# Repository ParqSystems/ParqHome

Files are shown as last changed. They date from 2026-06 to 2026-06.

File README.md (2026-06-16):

ParqHome is a smart home automation system that controls household appliances in real time through a combination of custom hardware, IoT protocols, and cloud infrastructure. Users toggle devices on a React Native dashboard, which publishes MQTT commands to an ESP8266 microcontroller. The ESP8266 controls relays to switch appliances instantly, and any state change syncs back through the cloud to keep the UI synchronized. Physical switches continue to work independently for local control, ensuring the system remains functional even if cloud connectivity is lost.

The system is built on a custom PCB with an ESP8266 (ESP-12F), relay driver circuits, power regulation, and protection mechanisms. Communication happens through MQTT via HiveMQ Cloud, while the backend uses Express.js with MongoDB Atlas for state management and API services. Python automation services handle reliable message routing, and a React Native frontend provides real-time device control and status updates. Every component was designed and tested to solve real-world challenges in synchronizing distributed embedded systems with cloud infrastructure.

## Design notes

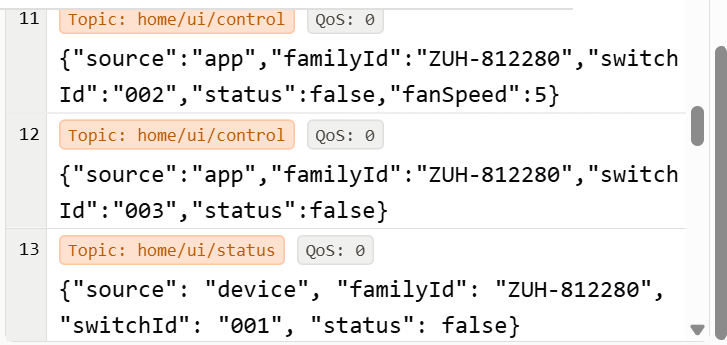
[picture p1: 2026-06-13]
Screenshot 2026-05-19 182810.png

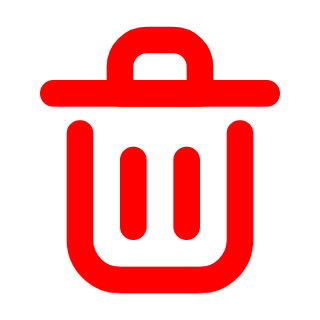
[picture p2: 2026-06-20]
Home Automation/home_automation_frontend/assets/delete-2-svgrepo-com.png

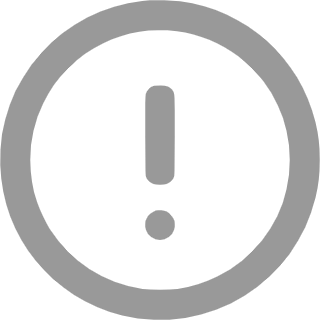
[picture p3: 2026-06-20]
Home Automation/home_automation_frontend/assets/error-16-svgrepo-com.png

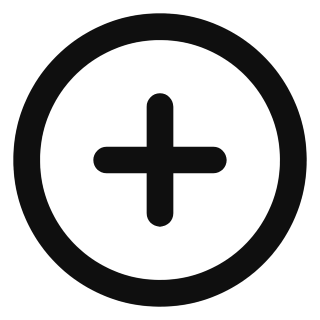
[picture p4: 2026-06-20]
Home Automation/home_automation_frontend/assets/add-ellipse-svgrepo-com.png

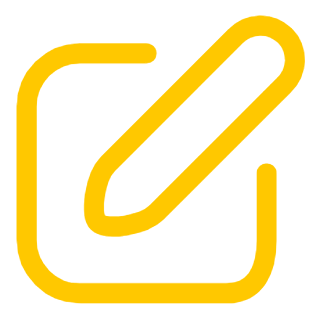
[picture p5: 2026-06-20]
Home Automation/home_automation_frontend/assets/edit-3-svgrepo-com.png

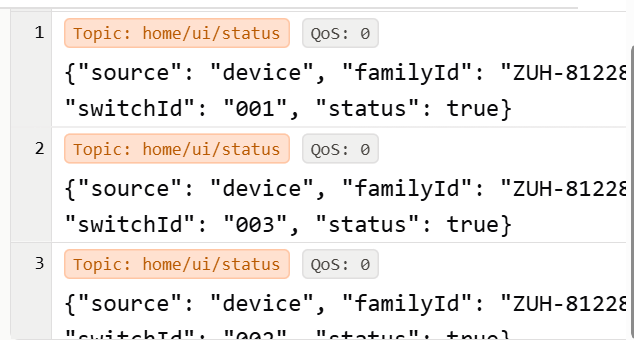
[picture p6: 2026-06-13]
Screenshot 2026-05-19 181907.png

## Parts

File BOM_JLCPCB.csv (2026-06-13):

Comment | Designator | Footprint | LCSC Part #
HLK-PM01 | U1 | HLK-PM01
5x20mm Fuse | F1 | Fuseholder_Clip-5x20mm
MOV 14D471 | MOV1 | MOV_Disc
AMS1117-3.3 | U2 | SOT-223
10uF | C1,C2 | C_ThroughHole
0.1uF | C3 | C_ThroughHole
ESP Module | U3 | ESP_Module
Relay 5V | K1, K2, K3 | Relay_THT
BC547 | Q1, Q2, Q3 | TO-92
1N4007 | D1, D2 ,D3 | DO-41
Terminal Block (2-pin) | J1, J3, J4 | TerminalBlock_2pin
Terminal Block (4-pin) | J2 | Connector_PinHeader_2.54mm:PinHeader_1x04_P2.54mm_Vertical
1k | R1 R2 R3 | Resistor_THT
10k | R4 R5 R6 | Resistor_THT
LED | LED1 LED2 | LED_THT
330? | R7 R8 | Resistor_THT
Test Point | TP1 TP2 | TestPoint

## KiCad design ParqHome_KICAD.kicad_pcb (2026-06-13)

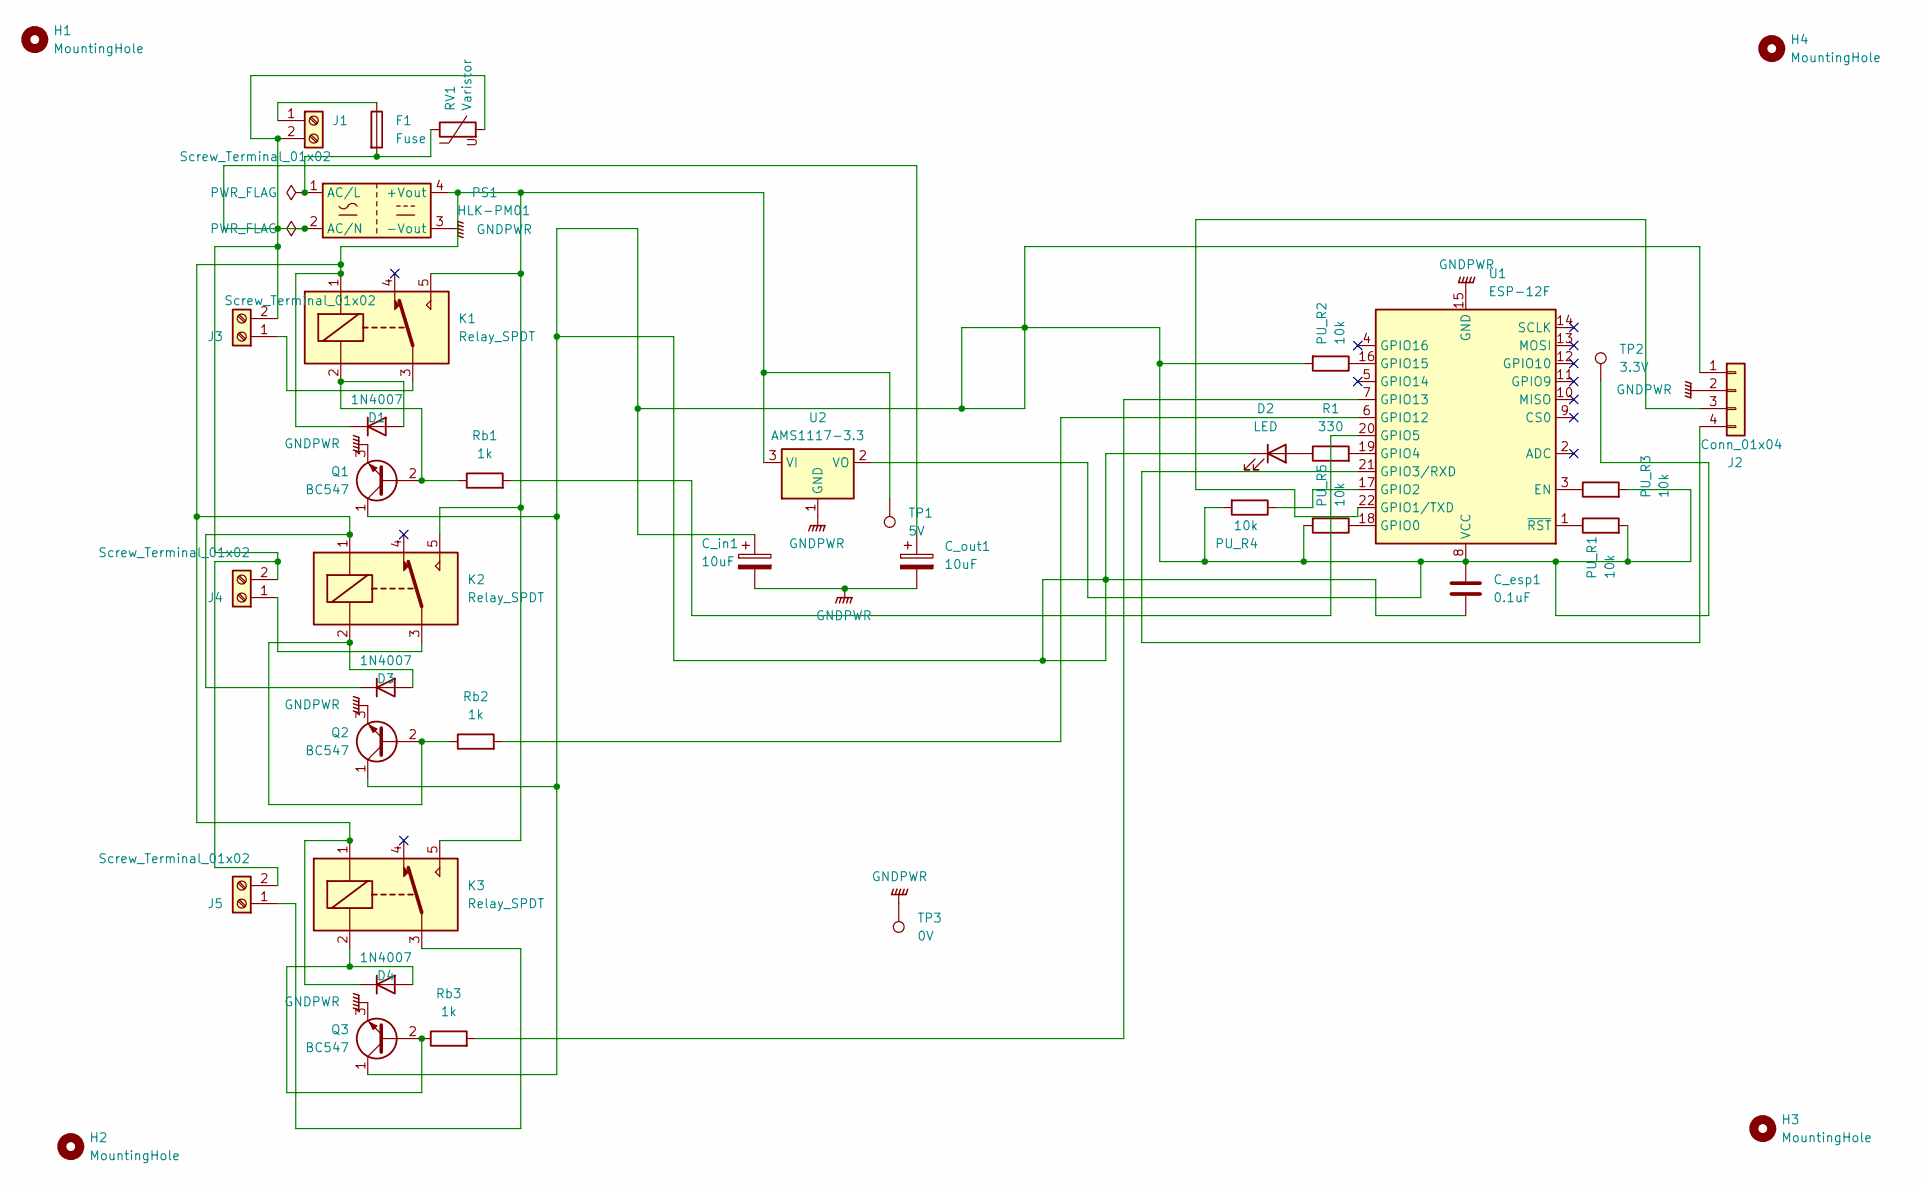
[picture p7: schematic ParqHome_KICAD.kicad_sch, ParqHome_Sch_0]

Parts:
C_esp1: 0.1uF; C_0805_2012Metric
C_in1: 10uF; CP_Radial_D6.3mm_P2.50mm
C_out1: 10uF; CP_Radial_D6.3mm_P2.50mm
D1, D3, D4: 1N4007; D_DO-41_SOD81_P10.16mm_Horizontal
D2: LED; LED_0805_2012Metric
F1: Fuse; Fuseholder_Clip-5x20mm_Littelfuse_520_Inline_P20.50x5.80mm_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
H1, H2, H3, H4: MountingHole; MountingHole_3.2mm_M3
J1, J3, J4, J5: Screw_Terminal_01x02; TerminalBlock_CUI_TB007-508-02_1x02_P5.08mm_Horizontal
J2: Conn_01x04; PinHeader_1x04_P2.54mm_Vertical
K1, K2, K3: Relay_SPDT; Relay_SPDT_SANYOU_SRD_Series_Form_C
PS1: HLK-PM01; Converter_ACDC_Hi-Link_HLK-PMxx
PU_R1, PU_R2, PU_R3, PU_R4, PU_R5: 10k; R_0805_2012Metric
Q1, Q2, Q3: BC547; TO-92_Inline
R1: 330; R_0805_2012Metric
RV1: Varistor; RV_Disc_D7mm_W3.4mm_P5mm
Rb1, Rb2, Rb3: 1k; R_0805_2012Metric
TP1: 5V; TestPoint_Bridge_Pitch2.54mm_Drill1.0mm
TP2: 3.3V; TestPoint_Bridge_Pitch2.54mm_Drill1.0mm
TP3: 0V; TestPoint_Bridge_Pitch2.54mm_Drill1.0mm
U1: ESP-12F; ESP-12E
U2: AMS1117-3.3; SOT-223-3_TabPin2

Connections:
GNDPWR: C_in1.2, C_out1.2, J2.2, PS1.3 (-Vout), Q1.3 (E), Q2.3 (E), Q3.3 (E), TP3.1, U1.15 (GND), U2.1 (GND)
unnamed: D1.2 (A), K1.2, Q1.2 (B), Rb1.1
unnamed: D1.1 (K), D3.1 (K), D4.1 (K), K1.1, K1.5, K2.1, K2.5, K3.1, K3.5, PS1.4 (+Vout), TP1.1, U2.3 (VI)
unnamed: D2.2 (A), R1.1
unnamed: C_esp1.1, C_esp1.2, C_in1.1, D2.1 (K), J2.1, PU_R1.2, PU_R2.2, PU_R3.2, PU_R4.2, PU_R5.2, Q1.1 (C), Q2.1 (C), Q3.1 (C), TP2.1, U1.8 (VCC), U2.2 (VO)
unnamed: D3.2 (A), K2.2, Q2.2 (B), Rb2.1
unnamed: D4.2 (A), K3.2, Q3.2 (B), Rb3.1
unnamed: F1.1, J1.1
unnamed: C_out1.1, J1.2, J3.2, J4.2, J5.2, PS1.2 (AC/N), RV1.2
unnamed: J2.3, U1.22 (GPIO1/TXD)
unnamed: J2.4, U1.21 (GPIO3/RXD)
unnamed: J3.1, K1.3
unnamed: J4.1, K2.3
unnamed: J5.1, K3.3
unnamed: F1.2, PS1.1 (AC/L), RV1.1
unnamed: PU_R3.1, U1.3 (EN)
unnamed: PU_R5.1, U1.18 (GPIO0)
unnamed: PU_R4.1, U1.17 (GPIO2)
unnamed: R1.2, U1.19 (GPIO4)
unnamed: Rb1.2, U1.20 (GPIO5)
unnamed: Rb2.2, U1.6 (GPIO12)
unnamed: Rb3.2, U1.7 (GPIO13)
unnamed: PU_R2.1, U1.16 (GPIO15)
unnamed: PU_R1.1, U1.1 (~RST)

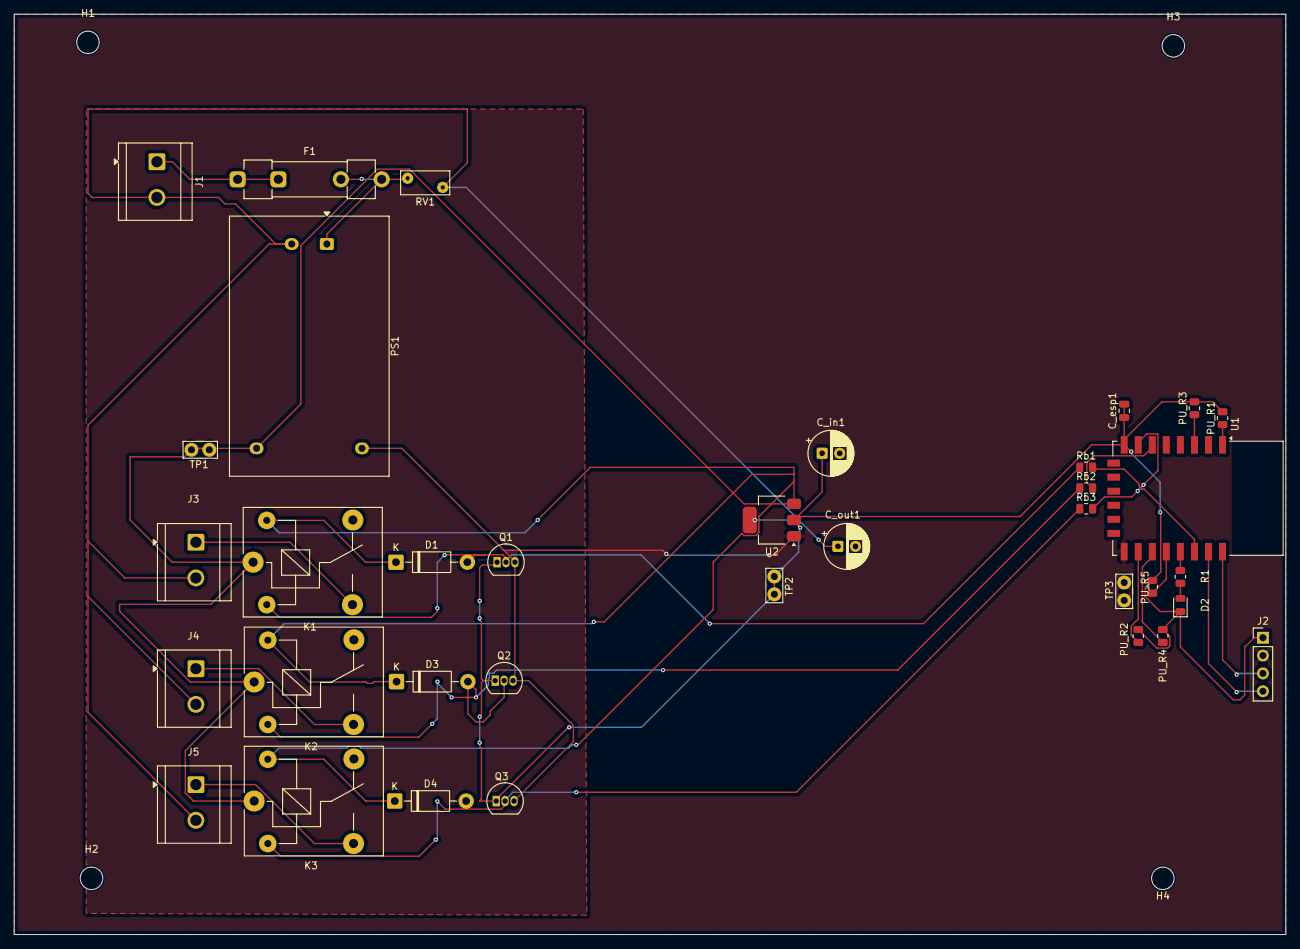
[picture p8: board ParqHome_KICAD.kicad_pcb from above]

Board: 2 copper layers, 181.0 x 131.0 mm, 39 parts (0 on the bottom side), 24 nets.

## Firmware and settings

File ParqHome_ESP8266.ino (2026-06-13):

#include <ESP8266WiFi.h>
#include <WiFiClientSecure.h>
#include <PubSubClient.h>

///////////////////////
// 🔌 PIN DEFINITIONS
///////////////////////
#define RELAY1 5
#define RELAY2 12
#define RELAY3 13

#define SW1 14
#define SW2 4
#define SW3 2

///////////////////////
// 📶 WIFI
///////////////////////
const char* ssid = "ICN 1st floor 4";
const char* password = "Akash@445";

///////////////////////
// 🌐 MQTT
///////////////////////
const char* mqtt_server = "8644400fc9e448468233fc0f9be265a0.s1.eu.hivemq.cloud";
const int mqtt_port = 8883;

const char* mqtt_user = "ParqHome_Hardware";
const char* mqtt_pass = "ParqHome_Hardware@123";

///////////////////////
// 👨‍👩‍👧 FAMILY ID
///////////////////////
const char* familyId = "ZUH-812280";

///////////////////////
// 📡 TOPICS
///////////////////////
const char* topic_control = "home/esp/control";
const char* topic_status  = "home/esp/status";

///////////////////////
// 🧠 STATE
///////////////////////
bool light1State = false;
bool light2State = false;
bool fanState    = false;

///////////////////////
// ⏱️ DEBOUNCE
///////////////////////
unsigned long lastDebounceTime[3] = {0,0,0};
const int debounceDelay = 200;

int lastSwitchState[3] = {HIGH, HIGH, HIGH};
bool pressed[3] = {false, false, false};

///////////////////////
// CLIENTS
///////////////////////
WiFiClientSecure espClient;
PubSubClient client(espClient);

///////////////////////
// 🔌 RELAY CONTROL
///////////////////////
void updateRelay(int pin, bool state) {
  digitalWrite(pin, state ? LOW : HIGH);
}

void applyStates() {
  updateRelay(RELAY1, light1State);
  updateRelay(RELAY2, light2State);
  updateRelay(RELAY3, fanState);
}

///////////////////////
// 📤 SEND STATUS
///////////////////////
void publishState() {

  String msg1 = "{\"source\":\"device\",\"familyId\":\"" + String(familyId) + "\",\"switchId\":\"001\",\"status\":" + String(light1State ? "true" : "false") + "}";
  String msg2 = "{\"source\":\"device\",\"familyId\":\"" + String(familyId) + "\",\"switchId\":\"002\",\"status\":" + String(light2State ? "true" : "false") + "}";
  String msg3 = "{\"source\":\"device\",\"familyId\":\"" + String(familyId) + "\",\"switchId\":\"003\",\"status\":" + String(fanState ? "true" : "false") + "}";

  client.publish(topic_status, msg1.c_str(), true);
  client.publish(topic_status, msg2.c_str(), true);
  client.publish(topic_status, msg3.c_str(), true);

  Serial.println("Status sent");
}

///////////////////////
// 📥 RECEIVE CONTROL
///////////////////////
void callback(char* topic, byte* payload, unsigned int length) {

  String msg = "";
  for (int i = 0; i < length; i++) msg += (char)payload[i];

  Serial.println("Received:");
  Serial.println(msg);

  // ✅ FIXED FAMILY CHECK (robust)
  if (msg.indexOf(familyId) < 0) {
    Serial.println("Ignored (wrong familyId)");
    return;
  }

  bool state = (msg.indexOf("\"status\":true") >= 0);

  if (msg.indexOf("\"switchId\":\"001\"") >= 0) {
    light1State = state;
    Serial.println("MQTT → Switch 1 → " + String(state ? "ON" : "OFF"));
  }

  else if (msg.indexOf("\"switchId\":\"002\"") >= 0) {
    light2State = state;
    Serial.println("MQTT → Switch 2 → " + String(state ? "ON" : "OFF"));
  }

  else if (msg.indexOf("\"switchId\":\"003\"") >= 0) {
    fanState = state;
    Serial.println("MQTT → Switch 3 → " + String(state ? "ON" : "OFF"));
  }

  applyStates();

  // ❌ NO publish here (prevents loop)
}

///////////////////////
// 📶 WIFI CONNECT
///////////////////////
void connectWiFi() {
  Serial.println("Connecting WiFi...");
  WiFi.begin(ssid, password);

  while (WiFi.status() != WL_CONNECTED) {
    delay(500);
    Serial.print(".");
  }

  Serial.println("\nWiFi Connected");
}

///////////////////////
// 🔁 MQTT CONNECT
///////////////////////
void reconnectMQTT() {
  while (!client.connected()) {

    Serial.println("Connecting MQTT...");

    String clientId = "ParqHome_" + String(ESP.getChipId());

    if (client.connect(clientId.c_str(), mqtt_user, mqtt_pass)) {

      Serial.println("MQTT Connected");

      client.subscribe(topic_control);

      publishState(); // sync UI on reconnect

    } else {
      Serial.print("Failed, rc=");
      Serial.println(client.state());
      delay(2000);
    }
  }
}

///////////////////////
// 🔘 SWITCH HANDLER
///////////////////////
void handleSwitch(int pin, int index, bool &stateVar, int switchId) {

  int reading = digitalRead(pin);

  if (reading != lastSwitchState[index]) {
    lastDebounceTime[index] = millis();
  }

  if ((millis() - lastDebounceTime[index]) > debounceDelay) {

    if (reading == LOW && !pressed[index]) {

      pressed[index] = true;
      stateVar = !stateVar;

      Serial.print("Switch ");
      Serial.print(switchId);
      Serial.print(" → ");
      Serial.println(stateVar ? "ON" : "OFF");

      applyStates();

      String msg = "{\"source\":\"device\",\"familyId\":\"" + String(familyId) +
                   "\",\"switchId\":\"00" + String(switchId) +
                   "\",\"status\":" + String(stateVar ? "true" : "false") + "}";

      client.publish(topic_status, msg.c_str(), true);
    }

    if (reading == HIGH) {
      pressed[index] = false;
    }
  }

  lastSwitchState[index] = reading;
}

///////////////////////
// ⚙️ SETUP
///////////////////////
void setup() {

  Serial.begin(115200);

  pinMode(RELAY1, OUTPUT);
  pinMode(RELAY2, OUTPUT);
  pinMode(RELAY3, OUTPUT);

  pinMode(SW1, INPUT_PULLUP);
  pinMode(SW2, INPUT_PULLUP);
  pinMode(SW3, INPUT_PULLUP);

  applyStates();

  connectWiFi();

  espClient.setInsecure();

  client.setServer(mqtt_server, mqtt_port);
  client.setCallback(callback);
}

///////////////////////
// 🔁 LOOP
///////////////////////
void loop() {

  if (!client.connected()) {
    Serial.println("MQTT disconnected, reconnecting...");
    reconnectMQTT();
  }

  client.loop();

  handleSwitch(SW1, 0, light1State, 1);
  handleSwitch(SW2, 1, light2State, 2);
  handleSwitch(SW3, 2, fanState, 3);

  delay(10);
}

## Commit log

2026-04-23 KiCad PCB Design upload
    [BOM_JLCPCB.csv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]
2026-06-13 Arduino code
